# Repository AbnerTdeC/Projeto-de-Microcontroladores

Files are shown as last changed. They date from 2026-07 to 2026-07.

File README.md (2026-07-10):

# 🚗 Projeto: Carrinho Robótico Arduino com Garra com Controle Remoto com Display TFT e Obstáculos

## 📖 Sobre o Projeto

Este repositório contém a documentação e os códigos para a montagem de um carrinho robótico customizado. O projeto une a versatilidade do **Arduino** com a mecânica do **LEGO**, resultando em um veículo capaz de se movimentar em todas as direções e manipular objetos através de uma garra articulada. O objetivo é colocar em uma pista para competir com outro carrinho feito por outro grupo com obstáculos feitos por ambos os grupos.

O diferencial do projeto é o seu **Controle Remoto Customizado**, que possui uma interface gráfica em um Display TFT, além de controle analógico via Joystick e botões de ação para a garra, assim como um obstáculo personalizado.

## ✨ Funcionalidades

* **Movimentação Omnidirecional/Tanque:** Tração gerada por 2 motores LEGO.
* **Manipulação de Objetos:** Garra frontal controlada de forma precisa por um Servo Motor.
* **Interface Visual:** Display TFT Shield no controle para exibir status (velocímetro, velocidade digital, bússola direcional, etc).
* **Controle Intuitivo:** Movimentação feita por um Joystick analógico.
* **Comunicação Sem Fio:** Conexão robusta via Bluetooth (Módulos HC-05).
* **Obstáculo** Passagem liberada por senha em Código Morse.

---

## 🛠️ Lista de Componentes

### 🚙 Para o Carrinho (Receptor)
* 1x Placa Arduino
* 1x Driver de Motor
* 2x Motores LEGO
* 1x Servo Motor (para a garra)
* 1x Módulo Bluetooth HC-05 (Configurado como Slave)
* 1x Chassi
* 2x Baterias

### 🎮 Para o Controle Remoto (Transmissor)
* 1x Arduino Mega
* 1x Shield Display LCD TFT (encaixado diretamente no Mega)
* 1x Módulo Joystick Analógico (Eixos X, Y e Botão Z/SW)
* 1x Módulo Botão Push-button (Ação adicional)
* 1x Módulo Bluetooth HC-05 (Configurado como Master)
* 1x LED (Código Morse)
* Fios Jumper e Protoboard

### ⛔ Para os Obstáculos
* 1x Sensor Fotoresistor LDR
* 3X Resistores (220 Ohms)
* 1x Display de 7 Segmentos
* Fios Jumper e Protoboard
* Papelão para construção e Papel para Tabela com Código Morse

### ⛏️ Ferramentas Necessárias
* Pistola de Cola Quente
* Ferro de solda / Estação de Solda
* Impressora 3D
* Baterias e Pilhas Recarregáveis
* Multímetro
* Fonte de Bancada
* Alicate Decapador
* Chaves Fenda e Philips

---

## ⚡ Esquema de Ligação - Controle Remoto

Abaixo está o diagrama esquemático das conexões físicas do controle remoto, construído com base na imagem do Fritzing fornecida.

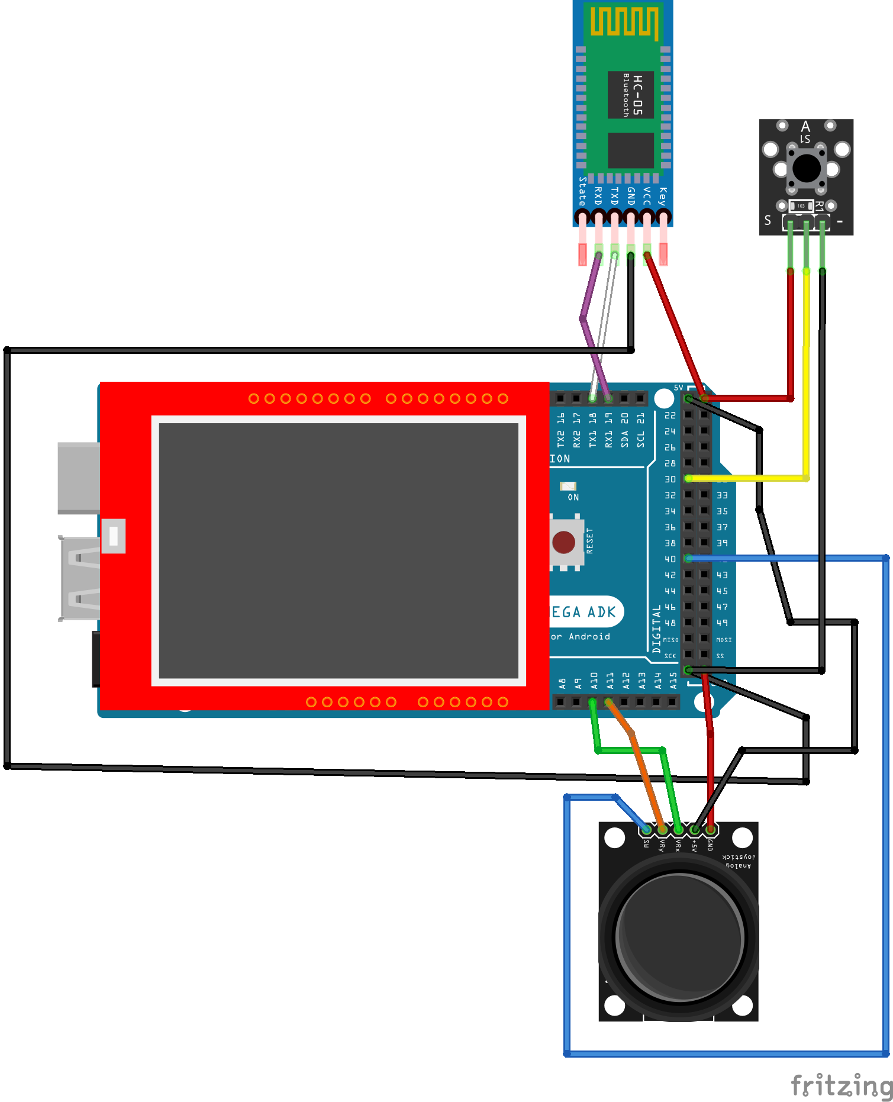
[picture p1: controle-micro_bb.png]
Esquemático do Controle


## ⚡ Esquema de Ligação - Carrinho

Abaixo está o diagrama esquemático das conexões físicas do controle remoto, construído com base na imagem do Fritzing fornecida.

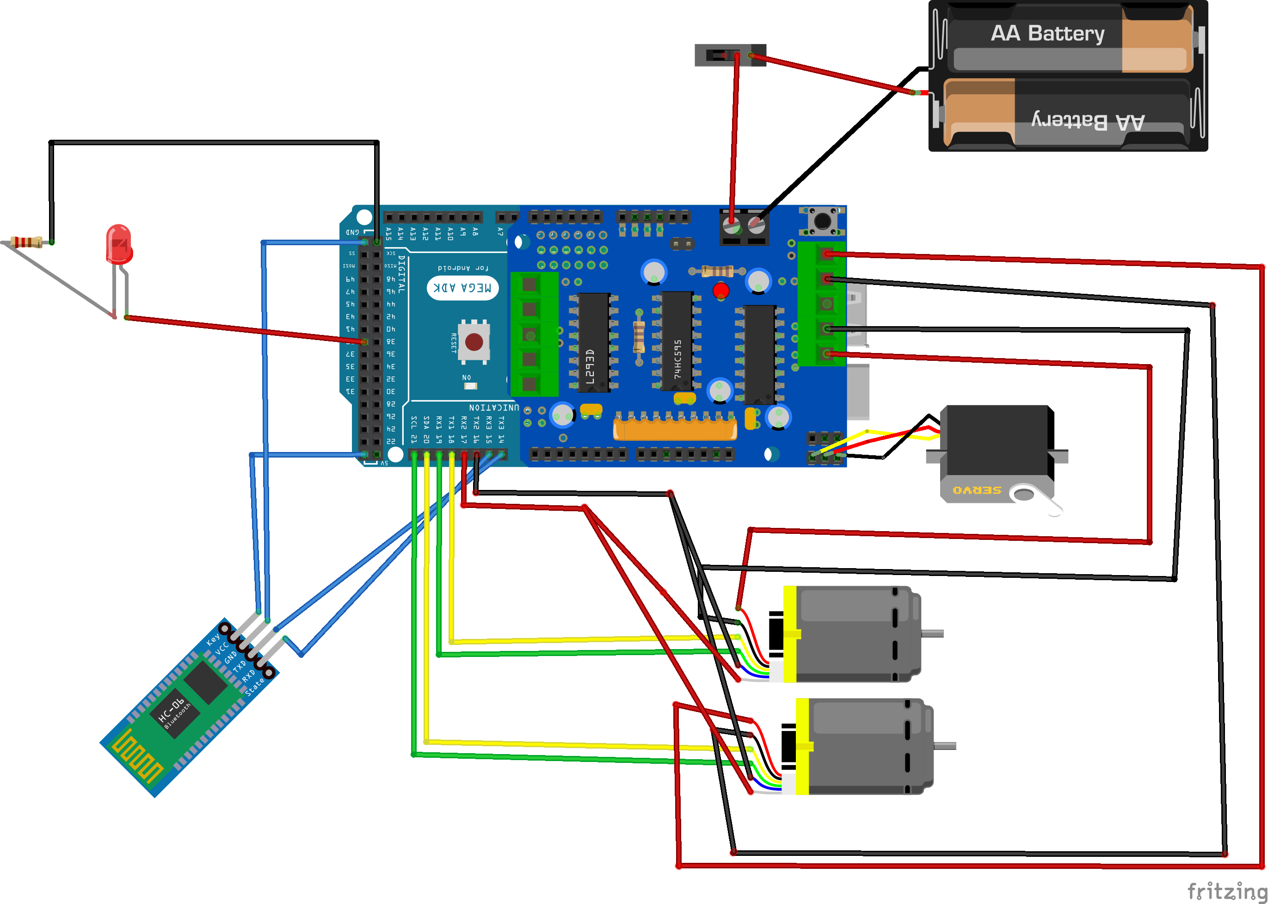
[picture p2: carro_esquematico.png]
Esquemático do Carrinho


## ⚡ Esquema de Ligação - Obstáculo

Abaixo está o diagrama esquemático das conexões físicas do controle remoto, construído com base na imagem do Fritzing fornecida.

Esquemático do Obstáculo

### 📌 Tabela de Conexões do Controle (Pinagem)

| Componente | Pino do Componente | Pino no Arduino Mega | Observações |
| :--- | :--- | :--- | :--- |
| **Shield TFT** | - | - | Encaixado diretamente sobre a placa. |
| **Módulo Bluetooth** | VCC | 5V | Alimentação |
| **Módulo Bluetooth** | GND | GND | Aterramento |
| **Módulo Bluetooth** | TXD | RX1 (Pino 19) | Comunicação Serial 1 |
| **Módulo Bluetooth** | RXD | TX1 (Pino 18) | Comunicação Serial 1 |
| **Joystick** | +5V | 5V | Alimentação |
| **Joystick** | GND | GND | Aterramento |
| **Joystick** | VRx | A9 | Eixo X Analógico |
| **Joystick** | VRy | A10 | Eixo Y Analógico |
| **Joystick** | SW (Botão 0) | Pino Digital 40 | Botão embutido no direcional |
| **Módulo Botão** | VCC | 5V | Alimentação |
| **Módulo Botão** | GND | GND | Aterramento |
| **Módulo Botão** | S (Sinal/Botão 1)| Pino Digital 30 | Botão para ação da garra |
| **Módulo Botão** | S (Sinal/Botão 2)| Pino Digital 26 | Botão para o LED do Código Morse |

---

## 🚀 Como Funciona

1. **Leitura dos Comandos:** O Arduino Mega lê constantemente as portas analógicas conectadas ao Joystick (A9 e A10) para determinar a direção e velocidade desejada. Simultaneamente, lê o estado dos pinos digitais 30 e 26 correspondentes aos botões.
2. **Atualização da Interface:** As informações de movimento e o status da garra podem ser desenhados (conforme necessário) no Display TFT utilizando bibliotecas como a `MCUFRIEND_kbv` 
3. **Transmissão:** Os dados de leitura são formatados em um pacote (ex: uma string de caracteres ou array de bytes) e enviados pela Serial 1 (Pinos 18 e 19) para o módulo Bluetooth HC-05 Master.
4. **Recepção e Ação:** O carrinho, equipado com o HC-05 Slave, recebe esses comandos, traduz em sinais PWM para o Driver de Motor (movendo os motores LEGO) e define o ângulo do Servo Motor (abrindo/fechando a garra).

## 🔧 Próximos Passos
* [ ] Publicar vídeos do desenvolvimento no YouTube.
* [ ] Finalizar o upload de todos arquivos.

---
*Projeto desenvolvido por Abner, Rafael e Tiago.*

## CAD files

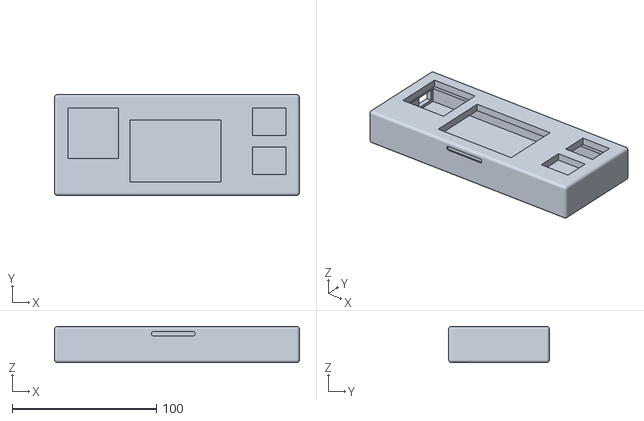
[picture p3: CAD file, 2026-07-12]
3D/caixa_controle.stl
170.0 x 70.0 x 25.0

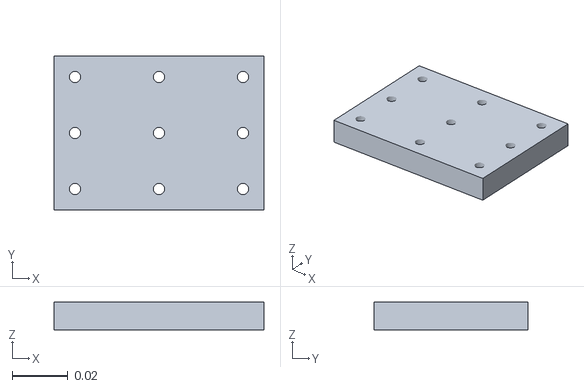
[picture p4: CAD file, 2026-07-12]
3D/suporte_arduino.stl
0.075 x 0.055 x 0.01

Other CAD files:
3D/teste_suporte_arduino.stl

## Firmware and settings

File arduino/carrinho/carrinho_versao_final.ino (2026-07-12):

#include <AFMotor.h>
#include <RotaryEncoder.h>
#include <Servo.h>

// registro velocidade
unsigned long instanteContagemTeste = 0;
unsigned long instanteContagem = 0;
int TicksPorRotacao = 180;
int pulsoInicialEsq = 0;
int pulsoInicialDir = 0;
int pulsosNoSegundoEsq = 0;
int pulsosNoSegundoDir = 0;
int velocidade = 0;
int velocidadeDir = 0;
int velocidadeEsq = 0;
int rpm = 0;
float velocidademedida = 0.0f;

// velocidade
float correcaoDir = 0.91f;
float angulo = 0.0;
float modulo = 0.0f;
int valorFinalModulo = 0;
float correcao = 0.0;
float multiDir = 0.0;
float multiEsq = 0.0;
String comando = "";

// MOTOR
AF_DCMotor motorEsquerda(1);
AF_DCMotor motorDireita(2);

// ENCODER
RotaryEncoder encoderEsquerda(18, 19);
RotaryEncoder encoderDireita(20, 21);
int posicaoEsquerdaAnterior = 0;
int posicaoDireitaAnterior = 0;

// Garra 
int pinoDoServo = 10;
Servo servo;
int estadoBotao1 = 0;

// led 
int estadoBotao2 = 0;
int led = 39;




////////////////////////////////////////////////////////////////////////////////////////////////////////////////////////////////////////////
void setup() {
  // Serial
  Serial.begin(9600);
  Serial.println("entrei");
  Serial3.begin(9600);

  // VCC E GROUND
  pinMode(16, OUTPUT);
  pinMode(17, OUTPUT);

  digitalWrite(16, LOW);
  digitalWrite(17, HIGH);

  // MOTOR
  motorEsquerda.setSpeed(255);
  motorDireita.setSpeed(255*correcaoDir);
  //motorEsquerda.run(FORWARD);
  //motorDireita.run(FORWARD);


  // Garra
  servo.attach(10);
  servo.write(0);

  // LED
  pinMode(led, OUTPUT);
  digitalWrite(led, HIGH);

  // ENCODER
  int origem1 = digitalPinToInterrupt(20);
  attachInterrupt(origem1, tickDoEncoderDireita, CHANGE);
  int origem2 = digitalPinToInterrupt(21);
  attachInterrupt(origem2, tickDoEncoderDireita, CHANGE);
  int origem3 = digitalPinToInterrupt(18);
  attachInterrupt(origem3, tickDoEncoderEsquerda, CHANGE);
  int origem4 = digitalPinToInterrupt(19);
  attachInterrupt(origem4, tickDoEncoderEsquerda, CHANGE);
}


void tickDoEncoderEsquerda() {
  encoderEsquerda.tick();
}

void tickDoEncoderDireita() {
  encoderDireita.tick();
}




////////////////////////////////////////////////////////////////////////////////////////////////////////////////////////////////////////////
void loop() {
  // MOTOR + VELOCIDADE
  if (Serial3.available() > 0) {
    String texto = Serial3.readStringUntil('\n');
    texto.trim();  // remove quebra de linha
    if (texto.startsWith("V")){
      int pos = texto.indexOf(':');
      int posVirgula = texto.indexOf(',');
      modulo = (texto.substring(pos + 1, posVirgula).toFloat());
      angulo = (texto.substring(posVirgula + 1).toFloat());
    }
    if (texto.startsWith("G")){
      estadoBotao1= (texto.substring(1).toFloat());
      if (estadoBotao1 == 0){
        servo.write(0);
      }
      else if (estadoBotao1 == 1){
        servo.write(25);
      }
    }
    if (texto.startsWith("L")){
      estadoBotao2= (texto.substring(1).toFloat());
      if (estadoBotao2 == 0){
        digitalWrite(led, LOW);
      }
      else if (estadoBotao2 == 1){
        digitalWrite(led, HIGH);
      }
    } 
    if (angulo > 0.0 && angulo < 90.0){
      multiEsq = (angulo / 90.0);
      multiDir = 1.0;
    } 
    else if (angulo > 90.0 && angulo < 180.0){
      multiEsq = 1.0;
      multiDir = 1.0 - ((angulo-90) / 90.0);
    }
    else if (angulo > 180.0 && angulo < 270.0){
      multiEsq = 1.0;
      multiDir = ((angulo-180) / 90.0);
    }
    else if (angulo > 270.0 && angulo < 360.0){
      multiEsq = 1-((angulo-270)/90.0);
      multiDir = 1.0;
    }
    else{
      multiDir = 1.0;
      multiEsq = 1.0;
    }

    valorFinalModulo = map(modulo, 0, 724, 0, 255);
    motorEsquerda.setSpeed(valorFinalModulo * multiEsq);
    motorDireita.setSpeed(valorFinalModulo * multiDir * correcaoDir);
    //Serial.print("velocidade Direita:");
   //Serial.print(valorFinalModulo * multiDir);
    //Serial.print("velocidade Esquerda:");
   //Serial.print(valorFinalModulo * multiEsq);

    //Serial.println(valorFinalModulo);
    //Serial.println("Modulo: " + String(modulo) + " Angulo: " + String(angulo));
    if (angulo > 0.00f && angulo < 180.00f) {
      comando = "Frente";
    }
    if (angulo > 180.00f && angulo < 360.00f) {
      comando = "Tras";
    }
    if (angulo == 180.00){
      comando = "Esquerda";
    } 
    if (angulo == 0.0 || angulo == 360.0) {
      comando = "Direita";
    }


      //rodar direcao
    /*if (texto.startsWith("DireitaF")) {
      int pos = texto.indexOf(':');
      velocidadeDir = texto.substring(pos + 1).toInt();
      Serial.println(velocidadeDir);
      motorDireita.setSpeed(velocidadeDir);
      motorDireita.run(FORWARD);
    }
    if (texto.startsWith("DireitaT")) {
      int pos = texto.indexOf(':');
      velocidadeDir = texto.substring(pos + 1).toInt();
      Serial.println(velocidadeDir);
      motorDireita.setSpeed(velocidadeDir);
      motorDireita.run(BACKWARD);
    }
    if (texto.startsWith("EsquerdaF")) {
      int pos = texto.indexOf(':');
      velocidadeEsq = texto.substring(pos + 1).toInt();
      //Serial.println(velocidadeEsq);
      motorEsquerda.setSpeed(velocidadeEsq);
      motorEsquerda.run(FORWARD);
    }
    if (texto.startsWith("EsquerdaT")) {
      int pos = texto.indexOf(':');
      velocidadeEsq = texto.substring(pos + 1).toInt();
      //Serial.println(velocidadeEsq);
      motorEsquerda.setSpeed(velocidadeEsq);
      motorEsquerda.run(BACKWARD);
    }
    Serial.println(comando);*/
    if (comando == "Frente") {
      motorEsquerda.run(FORWARD);
      motorDireita.run(FORWARD);
    }
    if (comando == "Tras") {
      motorEsquerda.run(BACKWARD);
      motorDireita.run(BACKWARD);
    }

    if (comando == "Esquerda") {
      motorEsquerda.run(FORWARD);
      motorDireita.run(BACKWARD);
    }
    if (comando == "Direita") {
      motorEsquerda.run(BACKWARD);
      motorDireita.run(FORWARD);
    }
    if (texto == "Parar") {
      motorEsquerda.run(RELEASE);
      motorDireita.run(RELEASE);
    }
    comando = "";

    /*if(botaoLED == true){
      digitalWrite(led, LOW);
    }
    else {
      digitalWrite(led, HIGH);
    }*/
  }


  // ENCODER
  int posicaoEsquerda = encoderEsquerda.getPosition();
  if (posicaoEsquerda != posicaoEsquerdaAnterior) {
    //Serial.println("posição esquerda: " + String(posicaoEsquerda));
  }
  posicaoEsquerdaAnterior = posicaoEsquerda;

  int posicaoDireita = encoderDireita.getPosition();
  if (posicaoDireita != posicaoDireitaAnterior) {
    //Serial.println("posição direita: " + String(posicaoDireita));
  }
  posicaoDireitaAnterior = posicaoDireita;

  // registro velocidade
  unsigned long instanteAtual = millis();
  if (instanteAtual > instanteContagem + 1000) {
    pulsosNoSegundoEsq = abs(posicaoEsquerda - pulsoInicialEsq);
    pulsosNoSegundoDir = abs(posicaoDireita - pulsoInicialDir);
    if (pulsosNoSegundoEsq >= pulsosNoSegundoDir) {
      rpm = (pulsosNoSegundoEsq * 60) / TicksPorRotacao;
    }
    if (pulsosNoSegundoDir > pulsosNoSegundoEsq) {
      rpm = (pulsosNoSegundoDir * 60) / TicksPorRotacao;
    }
    velocidademedida = ((rpm * PI * 56) / 60000) * 3.6f;
    pulsoInicialEsq = posicaoEsquerda;
    pulsoInicialDir = posicaoDireita;
    Serial3.print("v");
    Serial3.println(velocidademedida);
    instanteContagem = instanteAtual;
  }


  //teste dos encoders
  /*motorDireita.setSpeed(255*correcaoDir);
  motorEsquerda.setSpeed(255);
  motorEsquerda.run(FORWARD);
  motorDireita.run(FORWARD);
  if (instanteAtual > instanteContagemTeste + 1000) {
    Serial.println(posicaoEsquerda-posicaoDireita);
    instanteContagemTeste = instanteAtual;
  }*/
}

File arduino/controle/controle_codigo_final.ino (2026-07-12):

#include <Adafruit_GFX.h>
#include <MCUFRIEND_kbv.h>
#include <GFButton.h>
MCUFRIEND_kbv tela;

// Cores Custom
#define COR_VERDE_CLARO 0x9E66

// Velocidade Maxima
const int VEL_MAX = 15;

// Joystick
const int pinoX = A10;       // VRx
const int pinoY = A11;       // VRy
int pinoBotaoJoystick = 40;  // SW

// Botao Garra
GFButton botao(30);
GFButton botao2(26);

float velocidade = 10.0;
bool garraAberta = false;
int led = 0;

float velocidadeMedida = 0;

unsigned long tempoAtual = 0;
unsigned long tempoAnterior = 0;
const long intervalo = 1000;
int segundosCorrida = 0;
int minutosCorrida = 0;
char tempoDisplay[6];

const int xCentro = 80;
const int yCentro = 140;
const int raio = 70;
const int raioInt = 57;
int ultimoAngulo = 180;

void setup() {
  Serial.begin(9600);

  // Transmissao para o carrinho
  Serial1.begin(9600);

  // GFButton
  botao.setPressHandler(funcaoBotao);
  botao2.setPressHandler(funcaoBotao2Apertar);
  botao2.setReleaseHandler(funcaoBotao2Soltar);

  // Configuração dos pinos com resistor interno ativo
  pinMode(30, INPUT_PULLUP);  // Botao Garra
  pinMode(40, INPUT_PULLUP);  // Botao Joystick
  pinMode(26, INPUT_PULLUP);

  tela.begin(tela.readID());
  tela.fillScreen(TFT_BLACK);
  tela.setRotation(1);

  // Titulo Velocimetro
  tela.setTextSize(2);
  tela.setTextColor(TFT_WHITE);
  tela.setCursor(10, 20);
  tela.print("VELOCIMETRO");

  // Unidades de medida fixas
  tela.setTextSize(2);
  tela.setTextColor(TFT_YELLOW);
  tela.setCursor(265, 35);
  tela.print("km/h");

  // Bussola Direcional Estatica

  // Desenho do Arco do Velocímetro
  for (int i = 180; i >= 0; i--) {
    uint16_t cor;

    if (i > 145) cor = COR_VERDE_CLARO;
    else if (i > 115) cor = TFT_GREEN;
    else if (i > 75) cor = TFT_YELLOW;
    else if (i > 35) cor = TFT_ORANGE;
    else cor = TFT_RED;

    float rad = i * DEG_TO_RAD;

    int xExt = xCentro + raio * cos(rad);
    int yExt = yCentro - raio * sin(rad);
    int xInt = xCentro + raioInt * cos(rad);
    int yInt = yCentro - raioInt * sin(rad);

    tela.drawLine(xInt, yInt, xExt, yExt, cor);
  }
}

void loop() {
  botao.process();
  botao2.process();
  // Lê os valores analógicos do Joystick
  int valorX = analogRead(pinoX);
  int valorY = analogRead(pinoY);
  int xCentrado = valorX - 512;
  int yCentrado = valorY - 512;
  if (abs(xCentrado) < 60) xCentrado = 0;
  if (abs(yCentrado) < 60) yCentrado = 0;
  int anguloCarrinho = 0;  // Variável para armazenar o ângulo
  if (xCentrado != 0 || yCentrado != 0) {
    float radianos = atan2(yCentrado, xCentrado);
    anguloCarrinho = radianos * 180.0 / PI;
    if (anguloCarrinho < 0) {
      anguloCarrinho += 360;  // Normaliza de 0 a 360 graus
    }
  }
  float velMod = mod(yCentrado, xCentrado);
  // Serial.print("velMod: ");
  // Serial.println(velMod);
  float velMapeada = map(velMod, 0, 724, 0, VEL_MAX);
  velocidade = velMapeada / 10.0;

  // Cronômetro
  tempoAtual = millis();
  if (tempoAtual - tempoAnterior >= intervalo) {
    atualizarPonteiro(velocidadeMedida*10);
    tempoAnterior = tempoAtual;
    segundosCorrida++;
    // Cronometro
    if (segundosCorrida >= 60) {
      segundosCorrida = 0;
      minutosCorrida++;
    }
    tela.setTextSize(4);
    tela.setTextColor(TFT_BLACK);
    tela.setCursor(180, 120);
    tela.print(tempoDisplay);
    sprintf(tempoDisplay, "%02d:%02d", minutosCorrida, segundosCorrida);
    tela.setTextColor(TFT_WHITE);
    tela.setCursor(180, 120);
    tela.print(tempoDisplay);

    // Dados de Debug na Tela
    tela.setCursor(10, 220);
    tela.setTextSize(2);
    tela.setTextColor(TFT_WHITE, TFT_BLACK);
    tela.print("Debug: ");
    tela.print(" X: ");
    tela.print(valorX);
    tela.print(" Y: ");
    tela.print(valorY);
    tela.print("      ");

    // Sentido Frente / Tras (CIMA / BAIXO)

    tela.setCursor(190, 170);
    tela.setTextSize(3);

    // yCentrado (Eixo Y para acelerar/frear)
    if (yCentrado == 0) {
      tela.setTextColor(TFT_WHITE, TFT_BLACK);
      tela.print("Parado");
    } else if (yCentrado > 0) {
      tela.setTextColor(TFT_GREEN, TFT_BLACK);
      tela.print("Frente");
    } else {
      tela.setTextColor(TFT_RED, TFT_BLACK);
      tela.print("Tras  ");
    }

    // Bussola Direcional Dinamica (ESQUERDA / DIREITA)

    tela.fillRect(10, 180, 140, 10, TFT_BLACK);

    // Desenha a marcação base (cruzamento)
    tela.drawFastHLine(10, 190, 140, TFT_WHITE);
    tela.drawFastVLine(80, 170, 20, TFT_WHITE);

    // xCentrado (Eixo X para os lados)
    if (xCentrado != 0) {

      int larguraBarra = map(abs(xCentrado), 0, 512, 0, 60);

      if (xCentrado > 0) {
        // Movendo para a DIREITA
        tela.fillRect(80, 180, larguraBarra, 10, TFT_WHITE);
      } else {
        // Movendo para a ESQUERDA
        tela.fillRect(80 - larguraBarra, 180, larguraBarra, 10, TFT_WHITE);
      }
    }
    // Velocidade Digital na Tela
    tela.setCursor(170, 20);
    tela.setTextColor(TFT_YELLOW, TFT_BLACK);
    tela.setTextSize(4);
    if (velocidade < 0.5) {
      tela.print(0.0, 1);
    } else {
      tela.print(velocidade, 1);
    }
    tela.print(" ");
  }

  // Transmissão Serial para o Arduino do Carrinho
  Serial1.print("V:");
  Serial1.print(velMod);
  Serial1.print(",");
  Serial1.print(anguloCarrinho);
  Serial1.print("\r\n");

  // Recebimento da Velocidade
  if (Serial1.available() > 0) {
    String texto = Serial1.readStringUntil('\n');
    texto.trim();
    if (texto.startsWith("v")) { 
      velocidadeMedida = texto.substring(1).toFloat();
      Serial.println(velocidadeMedida);
    }
  }

  //delay(300);
}

void atualizarPonteiro(int valor) {
  if (valor > VEL_MAX) {
    valor = VEL_MAX;
  }

  int angulo = map(valor, 0, VEL_MAX, 180, 0);

  // Apaga ponteiro anterior
  float radAntigo = ultimoAngulo * DEG_TO_RAD;
  int xAntigo = xCentro + (raioInt - 4) * cos(radAntigo);
  int yAntigo = yCentro - (raioInt - 4) * sin(radAntigo);
  tela.drawLine(xCentro, yCentro, xAntigo, yAntigo, TFT_BLACK);

  // Linha do ponteiro
  float radNovo = angulo * DEG_TO_RAD;
  int xNovo = xCentro + (raioInt - 4) * cos(radNovo);
  int yNovo = yCentro - (raioInt - 4) * sin(radNovo);
  tela.drawLine(xCentro, yCentro, xNovo, yNovo, TFT_WHITE);

  // Pino Central
  tela.fillCircle(xCentro, yCentro, 8, TFT_WHITE);
  tela.drawCircle(xCentro, yCentro, 8, TFT_BLACK);

  ultimoAngulo = angulo;
}

float mod(int X, int Y) {
  // Serial.print("Entrada: ");
  // Serial.print(X);
  // Serial.print(" | ");
  // Serial.println(Y);
  float fx = X;
  float fy = Y;
  return sqrt(fx * fx + fy * fy);
}
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

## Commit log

2026-07-10 Atualizar tabela de conexões do controle
2026-07-12 Adicionar o resto dos arquivos
    [Esquematica obstaculo morse.fzz, caixa_controle.stl, controle-micro.fzz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]
2026-07-12 Rename Esquematica obstaculo morse.fzz to fritzFritzing/Esquematica_obstaculo_morse.fzz
    [Esquematica_obstaculo_morse.fzz]
